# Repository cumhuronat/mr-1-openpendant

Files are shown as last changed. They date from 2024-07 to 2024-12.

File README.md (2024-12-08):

# mr-1-openpendant
An opensource pendant project for MR-1 CNC

## Overview
This project implements an open-source pendant system for the MR-1 CNC machine, providing a user-friendly interface for machine control and monitoring.
The system consists of two main components and detailed documentation for them can be found within their respective submodules.

### Pendant
- Custom-designed handheld controller
- Features a display interface for machine status and control
- Built using ESP32-based hardware
- Includes software implementation for the user interface and control logic

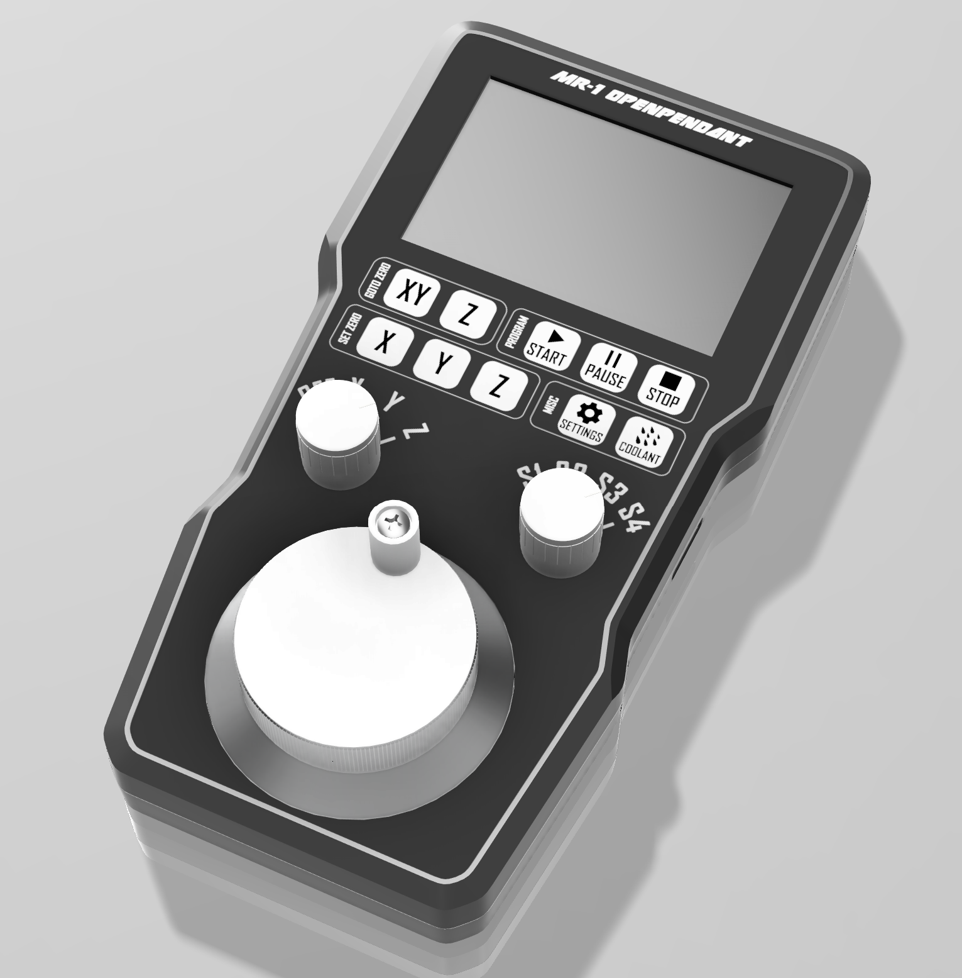
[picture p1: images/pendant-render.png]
Pendant Render

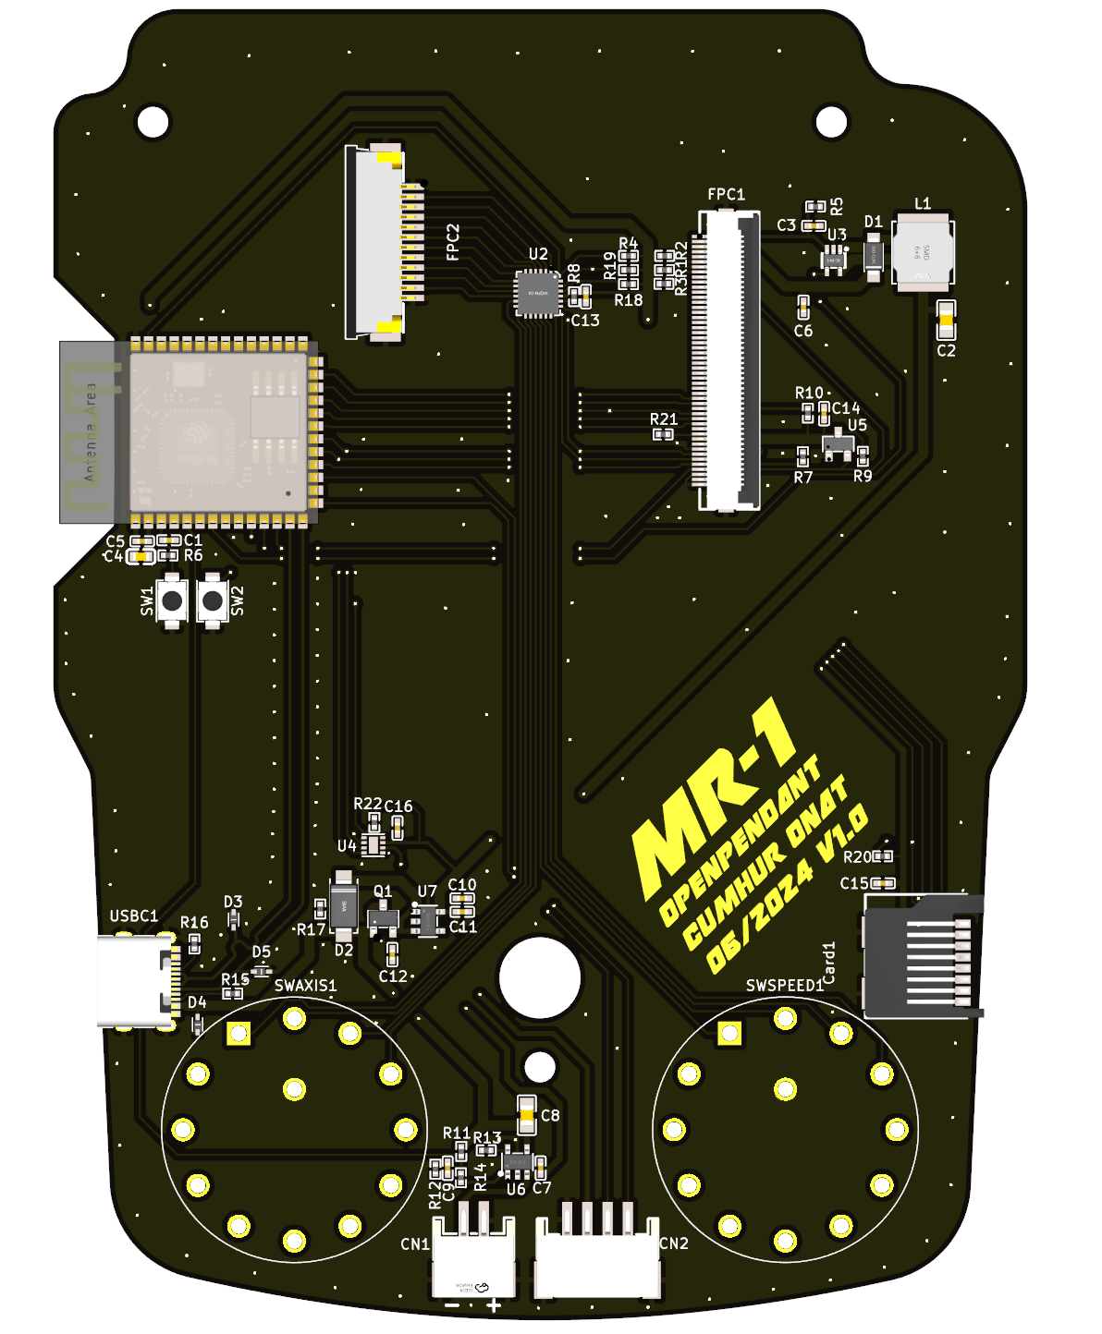
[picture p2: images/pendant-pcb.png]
Pendant PCB


### Dongle
- USB interface for CNC machine communication
- Components:
  - PCB design files
  - 3D-printable enclosure
  - Arduino-based firmware using TinyUSB
  - Interface software

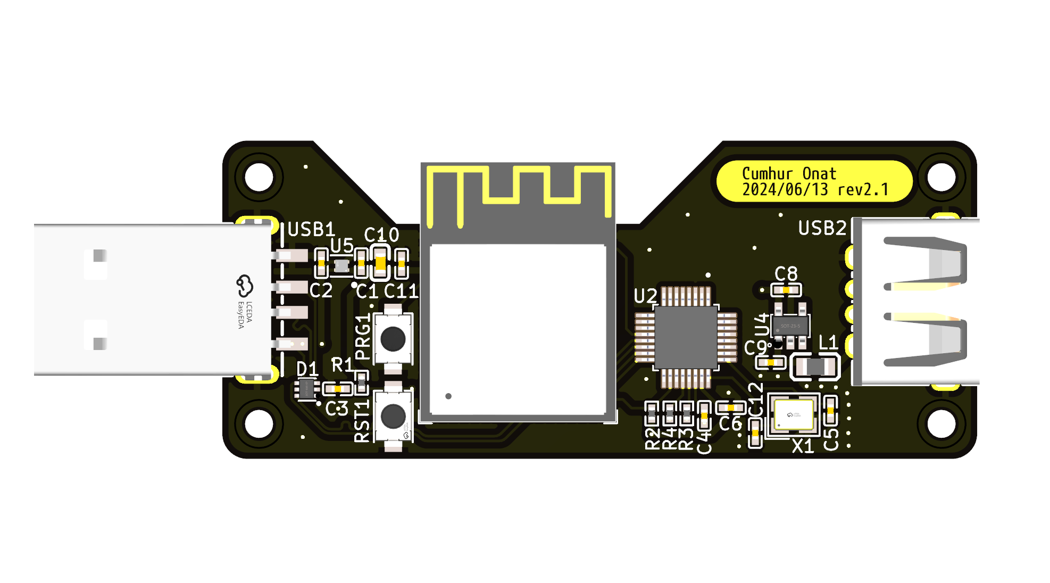
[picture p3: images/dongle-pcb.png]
Dongle PCB

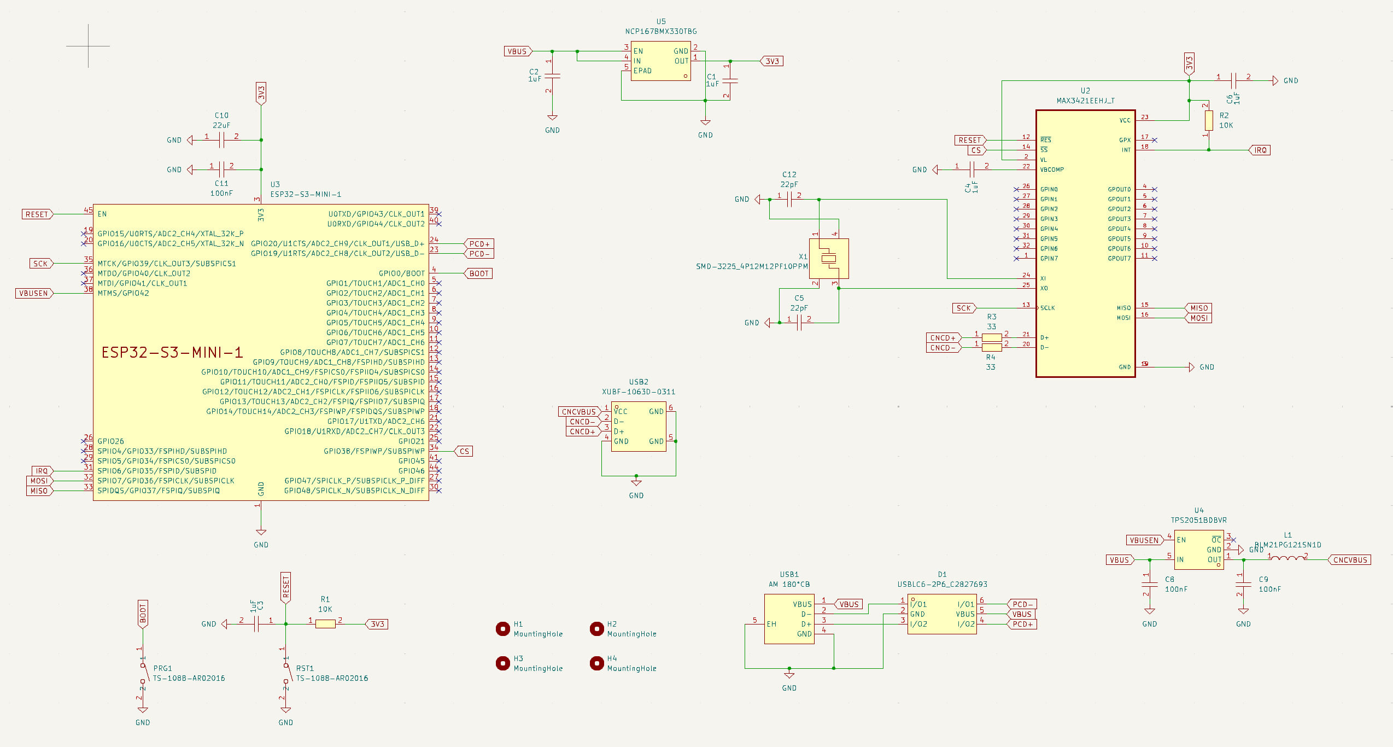
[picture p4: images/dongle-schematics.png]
Dongle Schematics


## Project Structure
- `/pendant` - Main pendant implementation
  - `/software` - Pendant firmware and interface code
- `/dongle` - USB interface dongle
  - `/enclosure` - 3D design files for the dongle case
  - `/pcb` - PCB design files
  - `/software` - Interface software

## Development Status
This project is currently under active development as part of the IMGD 5100 course final project.

## Acknowledgments
Special thanks to [Charlie Roberts](https://github.com/charlieroberts) for allowing this project to be developed as part of the IMGD 5100 final project.

## License
This project is open source and available under the[MIT License](https://opensource.org/licenses/MIT).

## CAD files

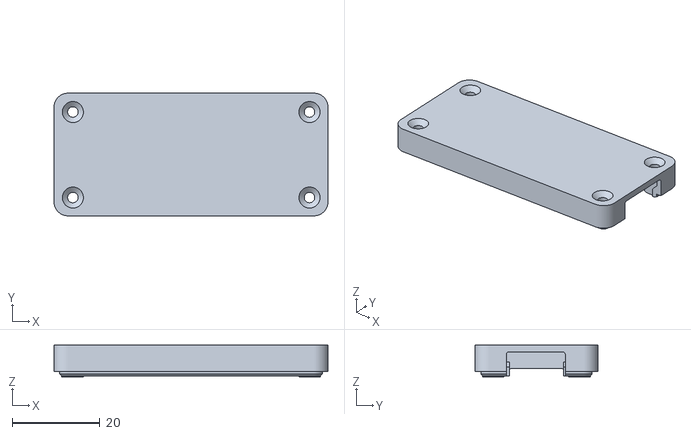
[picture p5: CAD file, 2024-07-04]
dongle/enclosure/top.stl
62.5 x 28.0 x 7.20

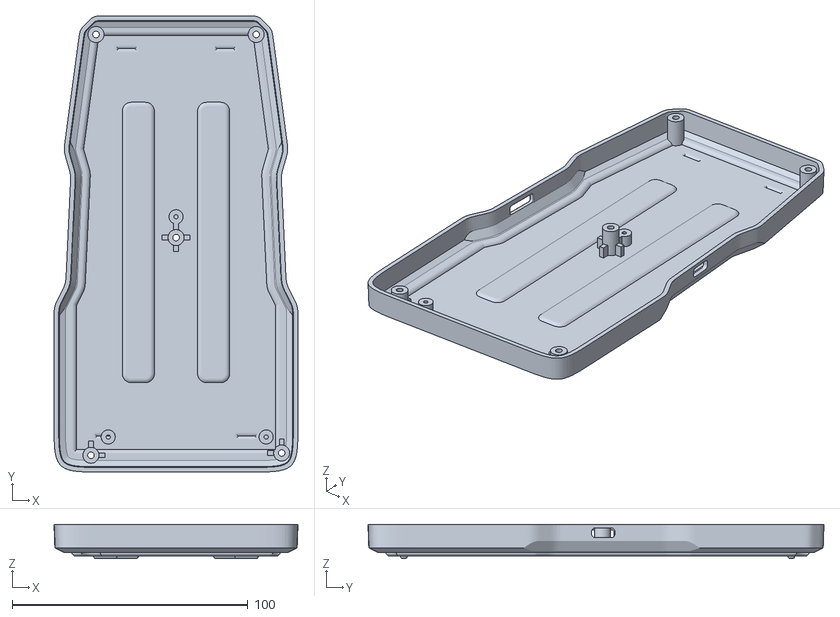
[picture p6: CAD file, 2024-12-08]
pendant/enclosure/BottomCover.stl
103.5 x 193.4 x 14.5

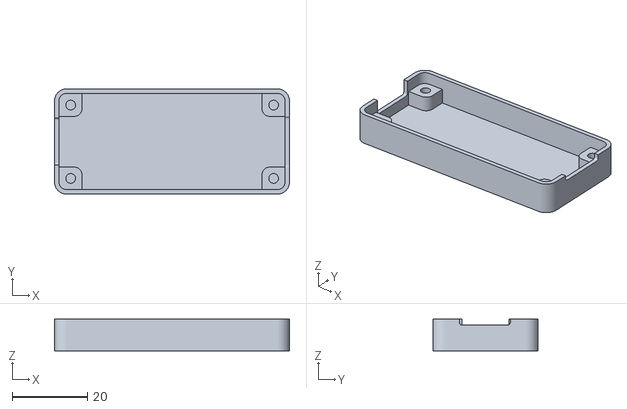
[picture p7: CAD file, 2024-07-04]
dongle/enclosure/bottom.stl
62.5 x 28.0 x 8.40

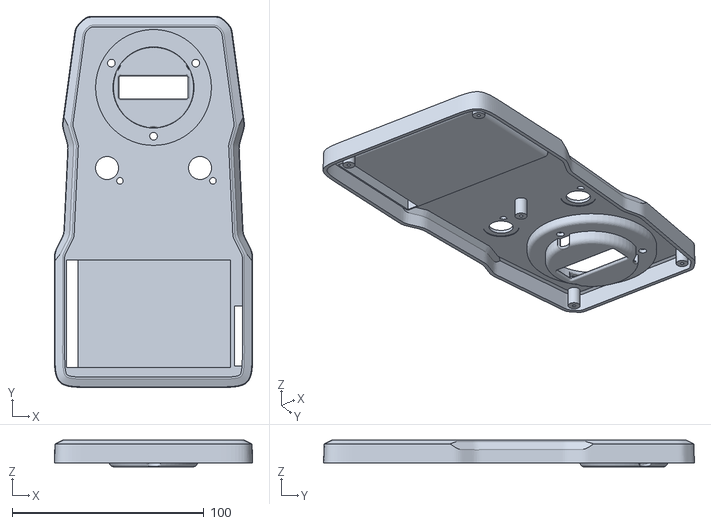
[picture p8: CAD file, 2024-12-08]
pendant/enclosure/TopCover.stl
103.5 x 193.4 x 14.0

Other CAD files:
dongle/enclosure/full.f3z

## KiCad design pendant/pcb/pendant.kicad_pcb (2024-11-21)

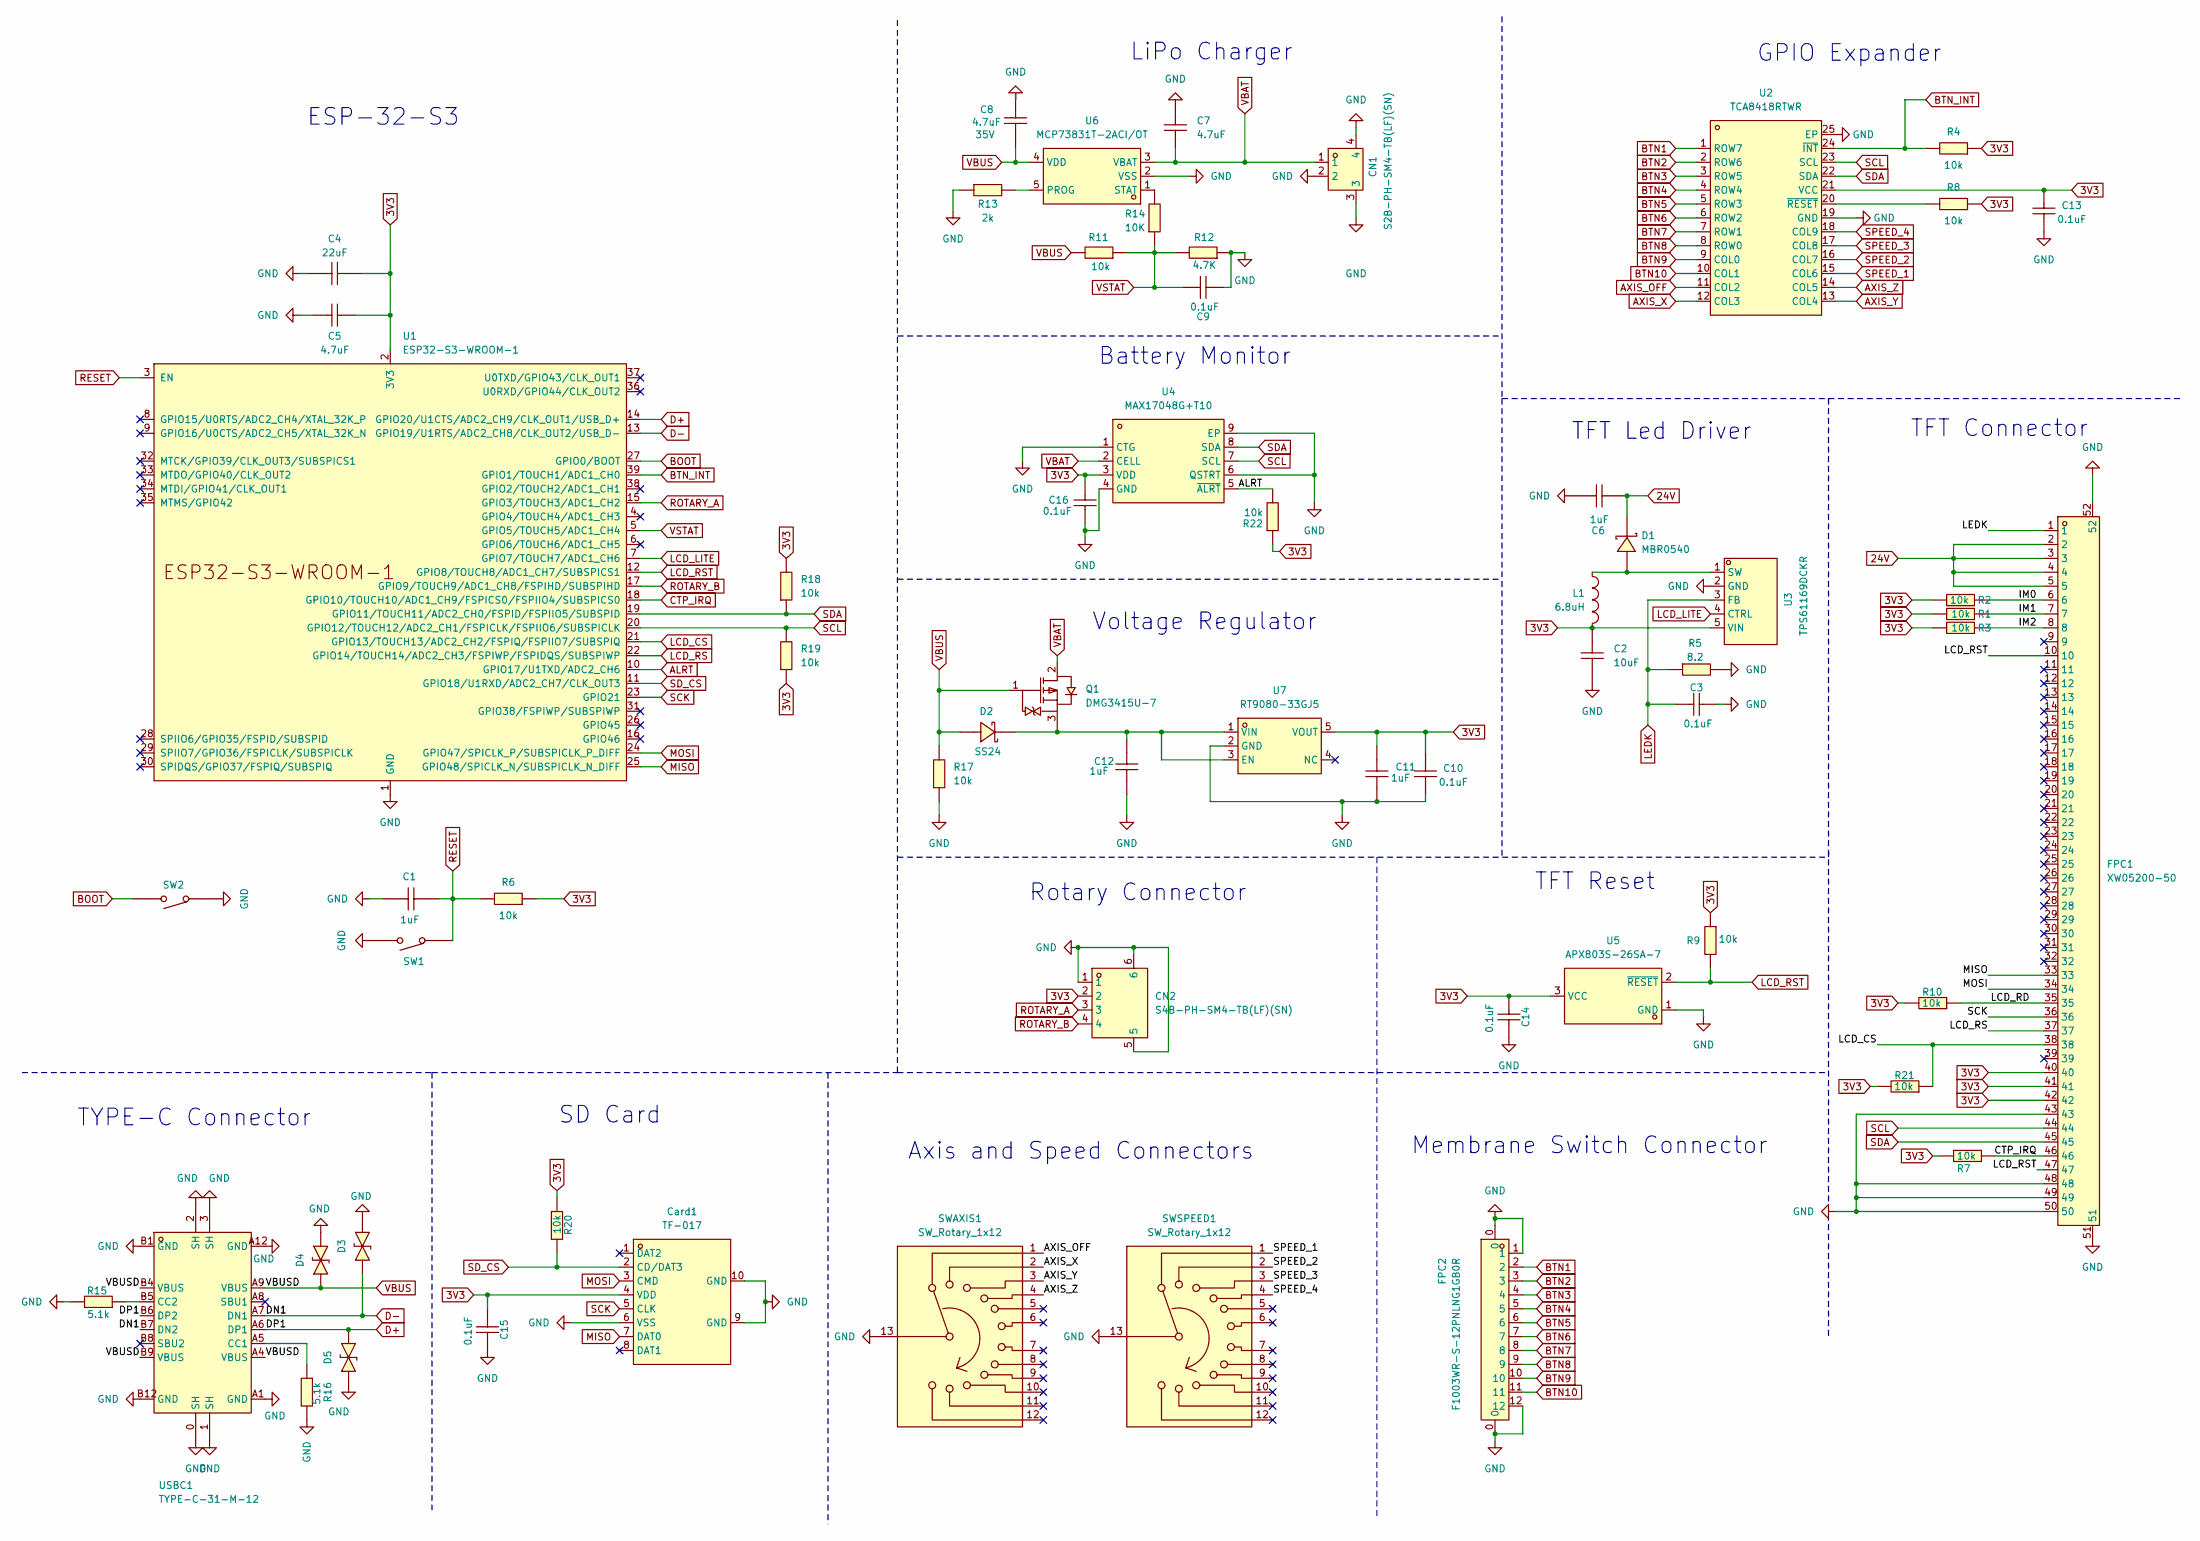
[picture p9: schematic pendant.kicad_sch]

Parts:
C1, C6, C11, C12: 1uF; C0402; LCSC Part C52923
C2: 10uF; C0805; LCSC Part C15850
C3, C9, C10, C13, C14, C15, C16: 0.1uF; C0402; LCSC Part C1525
C4: 22uF; C0603; LCSC Part C59461
C5, C7: 4.7uF; C0402; LCSC Part C23733
C8: 4.7uF; C0805; Voltage 35V; LCSC Part C668361
CN1: S2B-PH-SM4-TB(LF)(SN); CONN-SMD_P2.00_S2B-PH-SM4-TB-LF-SN; LCSC Part C295747
CN2: S4B-PH-SM4-TB(LF)(SN); CONN-SMD_S4B-PH-SM4-TB-LF-SN; LCSC Part C265102
Card1: TF-017; TF-SMD_TF-017; LCSC Part C410348
D1: MBR0540; SOD-123FL_L2.7-W1.8-LS3.8-RD; LCSC Part C116159
D2: SS24; SMA_L4.4-W2.8-LS5.4-R-RD; LCSC Part C489139
D3, D4, D5: LESD5D5.0CT1G; SOD-523_L1.2-W0.8-LS1.6-BI; LCSC Part C5246195
FPC1: XW05200-50; FPC-SMD_50P-P0.50_XW05200-50; LCSC Part C376073
FPC2: F1003WR-S-12PNLNG1GB0R; FPC-SMD_12P-P1.00_L5.5-W19.0; LCSC Part C247808
L1: 6.8uH; IND-SMD_L6.0-W6.0_SWPA6045S; LCSC Part C57254
Q1: DMG3415U-7; SOT-23-3_L2.9-W1.6-P1.90-LS2.8-BR-CW; LCSC Part C96616
R1, R2, R3, R4, R6, R7, R8, R9, R10, R11, R17, R18, R19, R20, R21, R22: 10k; R0402; LCSC Part C25744
R5: 8.2; R0402; LCSC Part C203098
R12: 4.7K; R0402; LCSC Part C140158
R13: 2k; R0402; LCSC Part C4109
R14: 10K; R0402; LCSC Part C25744
R15, R16: 5.1k; R0402; LCSC Part C25905
SW1, SW2: TS-1088-AR02016; SW-SMD_L3.9-W3.0-P4.45; LCSC Part C720477
SWAXIS1: SW_Rotary_1x12; CPA_12
SWSPEED1: SW_Rotary_1x12; CPA_12
U1: ESP32-S3-WROOM-1
U2: TCA8418RTWR; WQFN-24_L4.0-W4.0-P0.50-TL-EP2.5; LCSC Part C138713
U3: TPS61169DCKR; SC-70-5_L2.1-W1.3-P0.65-LS2.1-BR; LCSC Part C71045
U4: MAX17048G+T10; DFN-8_L2.0-W2.0-P0.50-BL-EP; LCSC Part C2682616
U5: APX803S-26SA-7; SOT-23-3_L2.9-W1.3-P1.83-LS2.4-BR; LCSC Part C526393
U6: MCP73831T-2ACI/OT; SOT-23-5_L3.0-W1.7-P0.95-LS2.8-BL; LCSC Part C424093
U7: RT9080-33GJ5; TSOT-23-5_L2.9-W1.6-P0.95-LS2.8-BL; LCSC Part C841192
USBC1: TYPE-C-31-M-12; USB-C_SMD-TYPE-C-31-M-12; LCSC Part C165948

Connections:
3V3: C2.2, C4.2, C5.2, C10.2, C11.1, C13.2, C14.1, C15.1, C16.1, CN2.2, Card1.4 (VDD), FPC1.40, FPC1.41, FPC1.42, L1.2, R1.2, R2.2, R3.2, R4.1, R6.1, R7.2, R8.1, R9.1, R10.2, R18.2, R19.1, R20.2, R21.2, R22.1, U1.2 (3V3), U2.21 (VCC), U3.5 (VIN), U4.3 (VDD), U5.3 (VCC), U7.5 (VOUT)
24V: C6.2, D1.1 (K), FPC1.2, FPC1.3, FPC1.4, FPC1.5
/IM0: FPC1.6, R2.1
/IM1: FPC1.7, R1.1
/IM2: FPC1.8, R3.1
/LCD_RD: FPC1.35, R10.1
ALRT: R22.2, U1.10 (GPIO17/U1TXD/ADC2_CH6), U4.5 (~ALRT)
AXIS_OFF: SWAXIS1.1, U2.11 (COL2)
AXIS_X: SWAXIS1.2, U2.12 (COL3)
AXIS_Y: SWAXIS1.3, U2.13 (COL4)
AXIS_Z: SWAXIS1.4, U2.14 (COL5)
BOOT: SW2.2, U1.27 (GPIO0/BOOT)
BTN1: FPC2.2, U2.1 (ROW7)
BTN2: FPC2.3, U2.2 (ROW6)
BTN3: FPC2.4, U2.3 (ROW5)
BTN4: FPC2.5, U2.4 (ROW4)
BTN5: FPC2.6, U2.5 (ROW3)
BTN6: FPC2.7, U2.6 (ROW2)
BTN7: FPC2.8, U2.7 (ROW1)
BTN8: FPC2.9, U2.8 (ROW0)
BTN9: FPC2.10, U2.9 (COL0)
BTN10: FPC2.11, U2.10 (COL1)
BTN_INT: R4.2, U1.39 (GPIO1/TOUCH1/ADC1_CH0), U2.24 (~INT)
CTP_IRQ: FPC1.46, R7.1, U1.18 (GPIO10/TOUCH10/ADC1_CH9/FSPICS0/FSPIIO4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)
D+: D5.1, U1.14 (GPIO20/U1CTS/ADC2_CH9/CLK_OUT1/USB_D+), USBC1.A6 (DP1), USBC1.B6 (DP2)
D-: D3.2, U1.13 (GPIO19/U1RTS/ADC2_CH8/CLK_OUT2/USB_D-), USBC1.A7 (DN1), USBC1.B7 (DN2)
GND: C1.2, C2.1, C3.2, C4.1, C5.1, C6.1, C7.2, C8.1, C9.2, C10.1, C11.2, C12.2, C13.1, C14.2, C15.2, C16.2, CN1.2, CN1.3, CN1.4, CN2.1, CN2.5, CN2.6, Card1.6 (VSS), Card1.9 (GND), Card1.10 (GND), D3.1, D4.1, D5.2, FPC1.43, FPC1.48, FPC1.49, FPC1.50, FPC1.51, FPC1.52, FPC2.0, FPC2.1, FPC2.12, R5.2, R12.1, R13.1, R15.2, R16.2, R17.1, SW1.2, SW2.1, SWAXIS1.13, SWSPEED1.13, U1.1 (GND), U1.40 (GND), U1.41 (GND), U2.19 (GND), U2.25 (EP), U3.2 (GND), U4.1 (CTG), U4.4 (GND), U4.6 (QSTRT), U4.9 (EP), U5.1 (GND), U6.2 (VSS), U7.2 (GND), USBC1.0 (SH), USBC1.1 (SH), USBC1.2 (SH), USBC1.3 (SH), USBC1.A1 (GND), USBC1.A12 (GND), USBC1.B1 (GND), USBC1.B12 (GND)
LCD_CS: FPC1.38, R21.1, U1.21 (GPIO13/TOUCH13/ADC2_CH2/FSPIQ/FSPIIO7/S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)
LCD_LITE: U1.7 (GPIO7/TOUCH7/ADC1_CH6), U3.4 (CTRL)
LCD_RS: FPC1.37, U1.22 (GPIO14/TOUCH14/ADC2_CH3/FSPIWP/FSPIDQS/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)
LCD_RST: FPC1.10, FPC1.47, R9.2, U1.12 (GPIO8/TOUCH8/ADC1_CH7/SUBSPICS1), U5.2 (~RESET)
LEDK: C3.1, FPC1.1, R5.1, U3.3 (FB)
MISO: Card1.7 (DAT0), FPC1.33, U1.25 (GPIO48/SPICLK_N/SUBSPICLK_N_DIFF)
MOSI: Card1.3 (CMD), FPC1.34, U1.24 (GPIO47/SPICLK_P/SUBSPICLK_P_DIFF)
unnamed: D1.2 (A), L1.1, U3.1 (SW)
unnamed: C12.1, D2.2 (K), Q1.3 (S), U7.1 (VIN), U7.3 (EN)
unnamed: R8.2, U2.20 (~RESET)
unnamed: R13.2, U6.5 (PROG)
unnamed: R14.2, U6.1 (STAT)
unnamed: R16.1, USBC1.A5 (CC1)
unnamed: R15.1, USBC1.B5 (CC2)
RESET: C1.1, R6.2, SW1.1, U1.3 (EN)
ROTARY_A: CN2.3, U1.15 (GPIO3/TOUCH3/ADC1_CH2)
ROTARY_B: CN2.4, U1.17 (GPIO9/TOUCH9/ADC1_CH8/FSPIHD/SUBSPIHD)
SCK: Card1.5 (CLK), FPC1.36, U1.23 (GPIO21)
SCL: FPC1.44, R19.2, U1.20 (GPIO12/TOUCH12/ADC2_CH1/FSPICLK/FSPIIO6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), U2.23 (SCL), U4.7 (SCL)
SDA: FPC1.45, R18.1, U1.19 (GPIO11/TOUCH11/ADC2_CH0/FSPID/FSPIIO5/S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), U2.22 (SDA), U4.8 (SDA)
SD_CS: Card1.2 (CD/DAT3), R20.1, U1.11 (GPIO18/U1RXD/ADC2_CH7/CLK_OUT3)
SPEED_1: SWSPEED1.1, U2.15 (COL6)
SPEED_2: SWSPEED1.2, U2.16 (COL7)
SPEED_3: SWSPEED1.3, U2.17 (COL8)
SPEED_4: SWSPEED1.4, U2.18 (COL9)
VBAT: C7.1, CN1.1, Q1.2 (D), U4.2 (CELL), U6.3 (VBAT)
VBUS: C8.2, D2.1 (A), D4.2, Q1.1 (G), R11.2, R17.2, U6.4 (VDD), USBC1.A4 (VBUS), USBC1.A9 (VBUS), USBC1.B4 (VBUS), USBC1.B9 (VBUS)
VSTAT: C9.1, R11.1, R12.2, R14.1, U1.5 (GPIO5/TOUCH5/ADC1_CH4)

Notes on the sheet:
Axis and Speed Connectors
ESP-32-S3
Rotary Connector
Battery Monitor
TFT Reset
SD Card
Membrane Switch Connector
LiPo Charger
TYPE-C Connector
GPIO Expander
Voltage Regulator
TFT Connector
TFT Led Driver

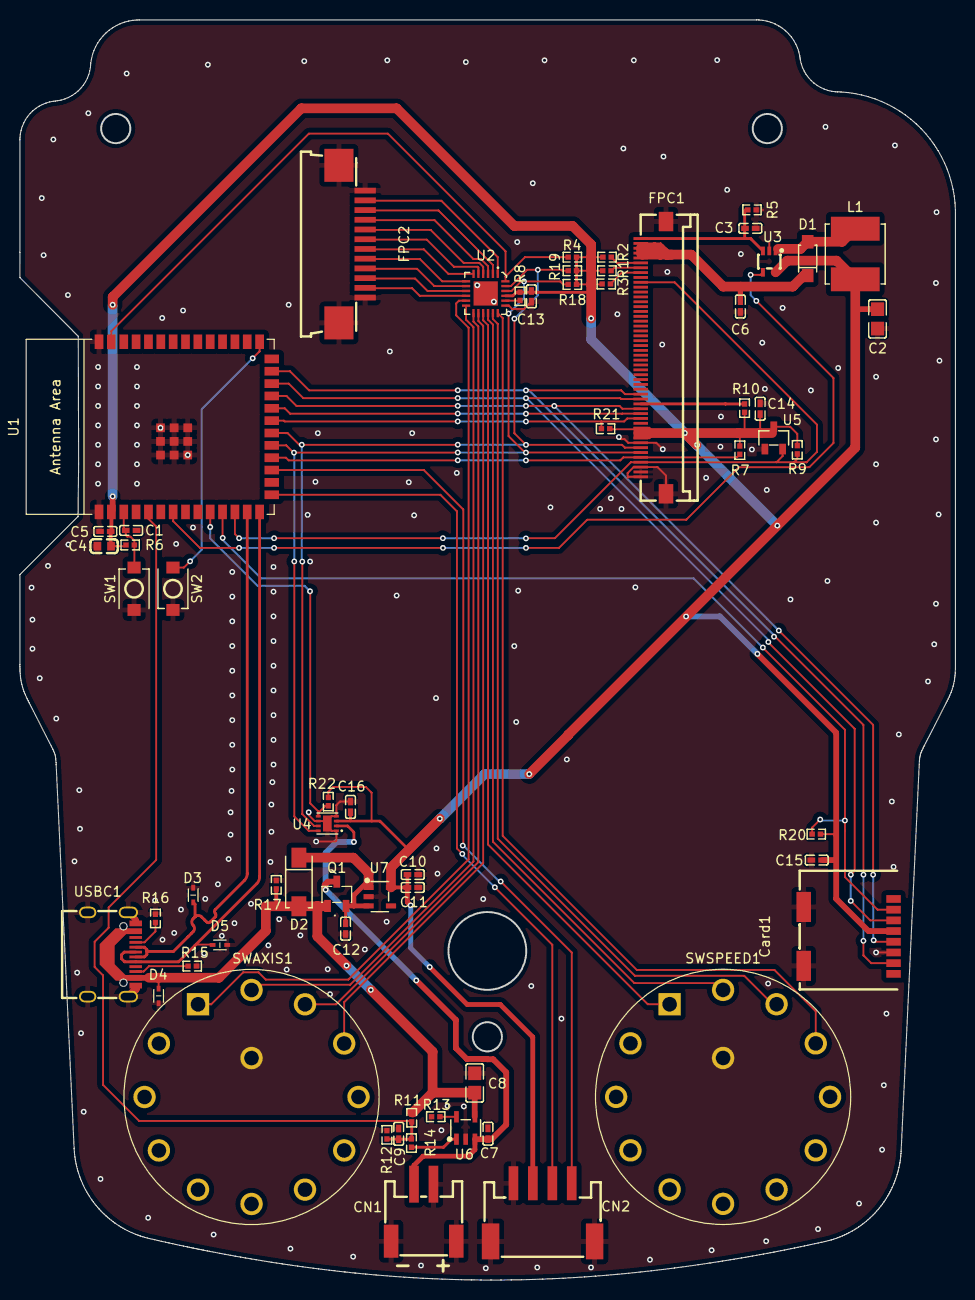
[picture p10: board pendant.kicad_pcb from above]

Board: 2 copper layers, 96.2 x 129.6 mm, 62 parts (0 on the bottom side), 55 nets.

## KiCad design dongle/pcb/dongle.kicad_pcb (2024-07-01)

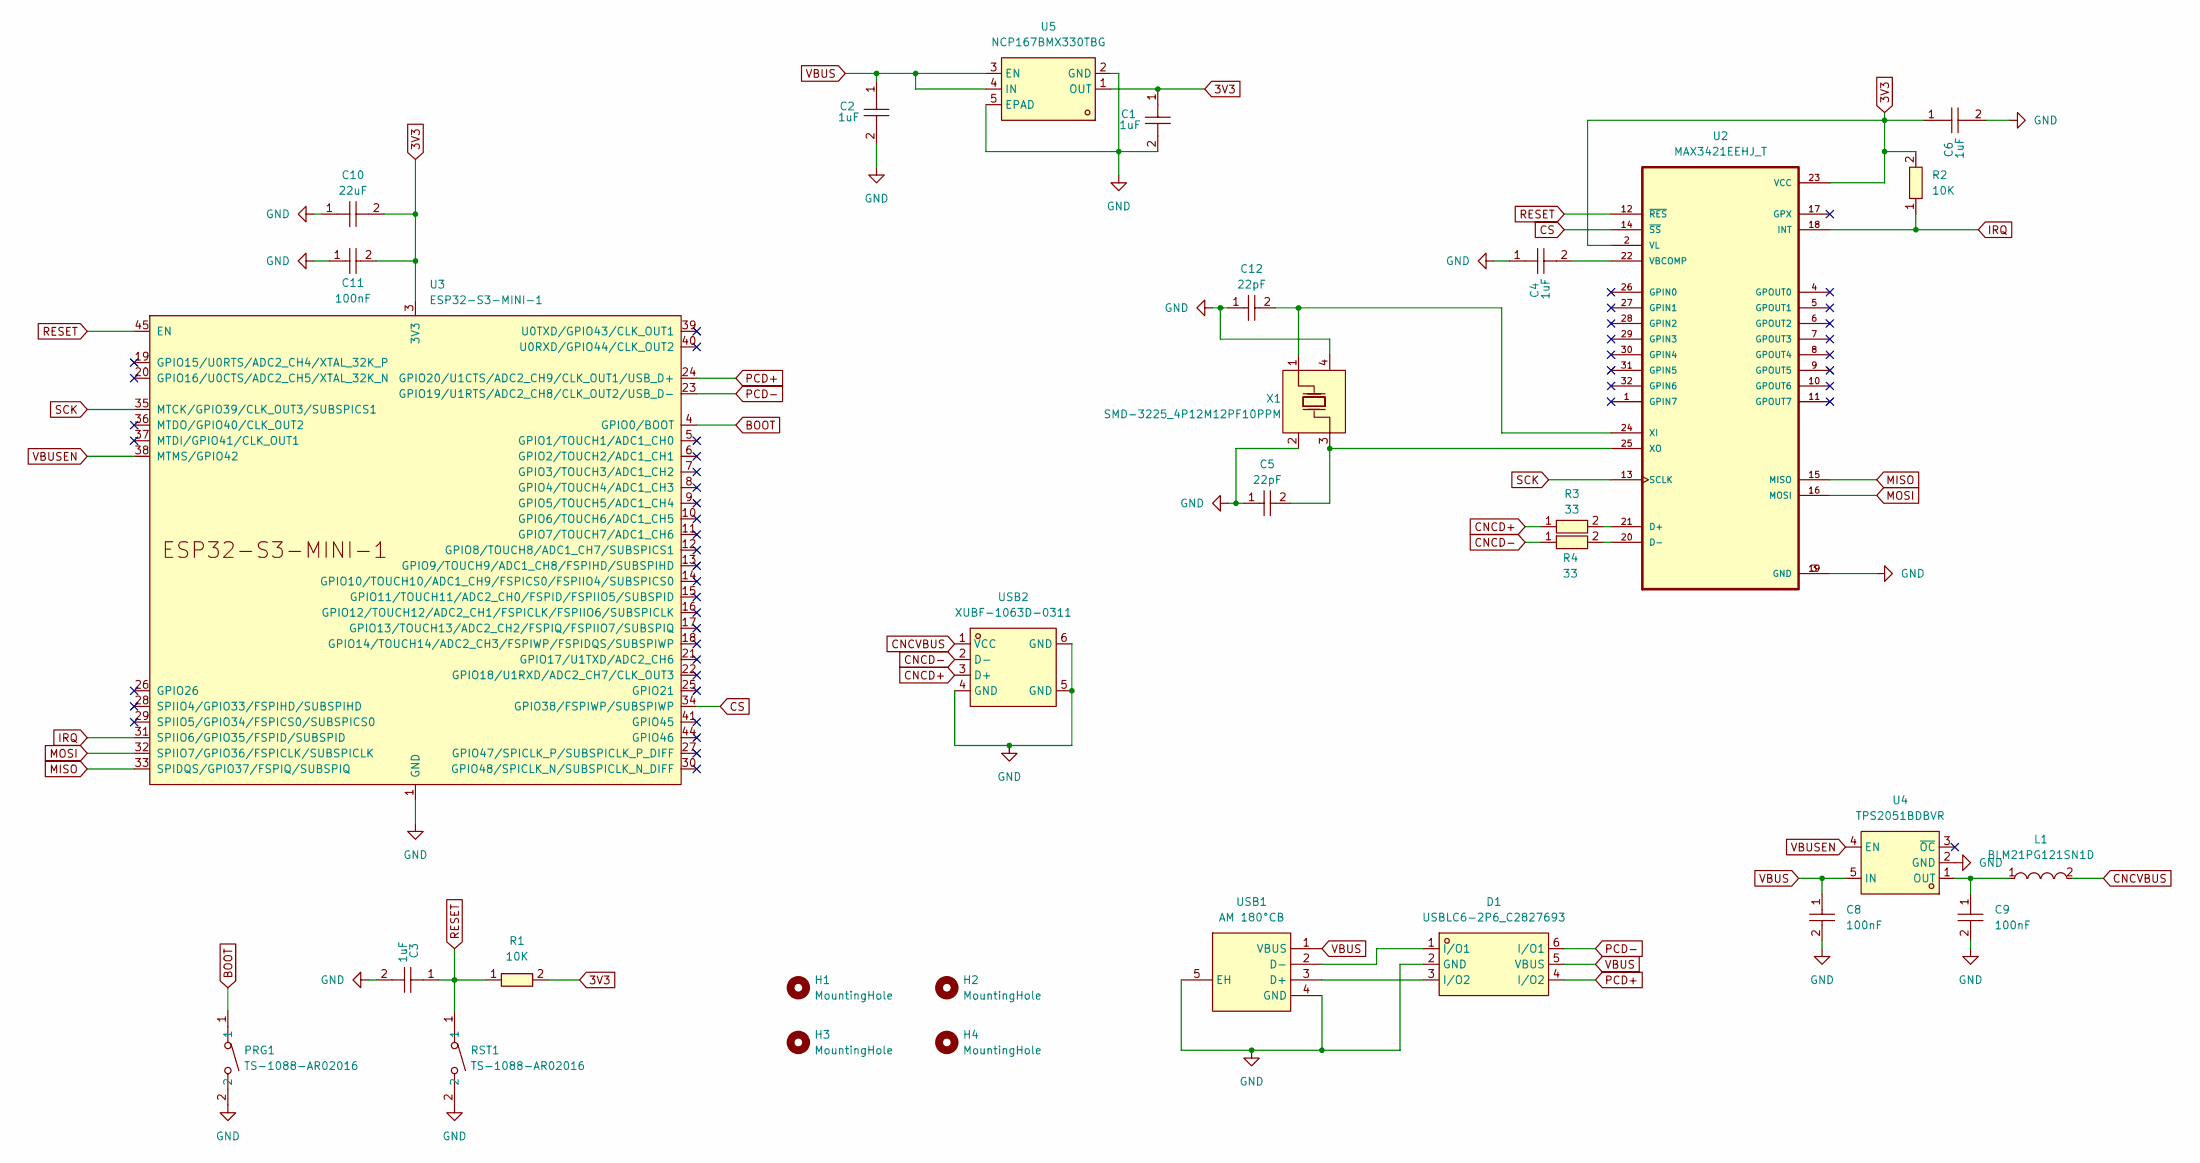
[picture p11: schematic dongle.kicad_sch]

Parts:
C1, C2, C3, C4, C6: 1uF; C0402; LCSC Part C52923
C5, C12: 22pF; C0402; LCSC Part C1555
C8, C9, C11: 100nF; C0402; LCSC Part C1525
C10: 22uF; C0603; LCSC Part C59461
D1: USBLC6-2P6_C2827693; SOT-666-6_L1.6-W1.2-P0.50-LS1.6-BL; LCSC Part C2827693
H1, H2, H3, H4: MountingHole; MountingHole_2.2mm_M2_DIN965
L1: BLM21PG121SN1D; L0805; LCSC Part C79382
PRG1: TS-1088-AR02016; SW-SMD_L3.9-W3.0-P4.45; LCSC Part C720477
R1, R2: 10K; R0402; LCSC Part C25744
R3, R4: 33; R0402; LCSC Part C25105
RST1: TS-1088-AR02016; SW-SMD_L3.9-W3.0-P4.45; LCSC Part C720477
U2: MAX3421EEHJ_T; QFP50P700X700X120-32N
U3: ESP32-S3-MINI-1
U4: TPS2051BDBVR; SOT-23-5_L3.0-W1.7-P0.95-LS2.8-BR; LCSC Part C24593
U5: NCP167BMX330TBG; onsemi-711AJ-03_2022-C-MFG; LCSC Part C892227
USB1: AM 180°CB; USB-SMD_AM180CB; LCSC Part C2681565
USB2: XUBF-1063D-0311; USB-A-TH_XUBF-1063D-0311; LCSC Part C7527653
X1: SMD-3225_4P12M12PF10PPM; CRYSTAL-SMD_4P-L3.2-W2.5-BL; LCSC Part C133337

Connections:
3V3: C1.1, C6.1, C10.2, C11.2, R1.2, R2.2, U2.2 (VL), U2.23 (VCC), U3.3 (3V3), U5.1 (OUT)
BOOT: PRG1.1, U3.4 (GPIO0/BOOT)
CNCD+: R3.1, USB2.3 (D+)
CNCD-: R4.1, USB2.2 (D-)
CNCVBUS: L1.2, USB2.1 (VCC)
CS: U2.14 (~SS), U3.34 (GPIO38/FSPIWP/SUBSPIWP)
GND: C1.2, C2.2, C3.2, C4.1, C5.1, C6.2, C8.2, C9.2, C10.1, C11.1, C12.1, D1.2 (GND), PRG1.2, RST1.2, U2.3 (GND), U2.19 (GND), U3.1 (GND), U3.2 (GND), U3.42 (GND), U3.43 (GND), U3.46 (GND), U3.47 (GND), U3.48 (GND), U3.49 (GND), U3.50 (GND), U3.51 (GND), U3.52 (GND), U3.53 (GND), U3.54 (GND), U3.55 (GND), U3.56 (GND), U3.57 (GND), U3.58 (GND), U3.59 (GND), U3.60 (GND), U3.61 (GND), U3.62 (GND), U3.63 (GND), U3.64 (GND), U3.65 (GND), U4.2 (GND), U5.2 (GND), U5.5 (EPAD), USB1.4 (GND), USB1.5 (EH), USB2.4 (GND), USB2.5 (GND), USB2.6 (GND), X1.2 (GND), X1.4 (GND)
IRQ: R2.1, U2.18 (INT), U3.31 (SPIIO6/GPIO35/FSPID/SUBSPID)
MISO: U2.15 (MISO), U3.33 (SPIDQS/GPIO37/FSPIQ/SUBSPIQ)
MOSI: U2.16 (MOSI), U3.32 (SPIIO7/GPIO36/FSPICLK/SUBSPICLK)
unnamed: R3.2, U2.21 (D+)
unnamed: R4.2, U2.20 (D-)
unnamed: C4.2, U2.22 (VBCOMP)
unnamed: C12.2, U2.24 (XI), X1.1 (OSC1)
unnamed: C5.2, U2.25 (XO), X1.3 (OSC2)
unnamed: C9.1, L1.1, U4.1 (OUT)
unnamed: D1.3 (I/O2), USB1.3 (D+)
unnamed: D1.1 (I/O1), USB1.2 (D-)
PCD+: D1.4 (I/O2), U3.24 (GPIO20/U1CTS/ADC2_CH9/CLK_OUT1/USB_D+)
PCD-: D1.6 (I/O1), U3.23 (GPIO19/U1RTS/ADC2_CH8/CLK_OUT2/USB_D-)
RESET: C3.1, R1.1, RST1.1, U2.12 (~RES), U3.45 (EN)
SCK: U2.13 (SCLK), U3.35 (MTCK/GPIO39/CLK_OUT3/SUBSPICS1)
VBUS: C2.1, C8.1, D1.5 (VBUS), U4.5 (IN), U5.3 (EN), U5.4 (IN), USB1.1 (VBUS)
VBUSEN: U3.38 (MTMS/GPIO42), U4.4 (EN)

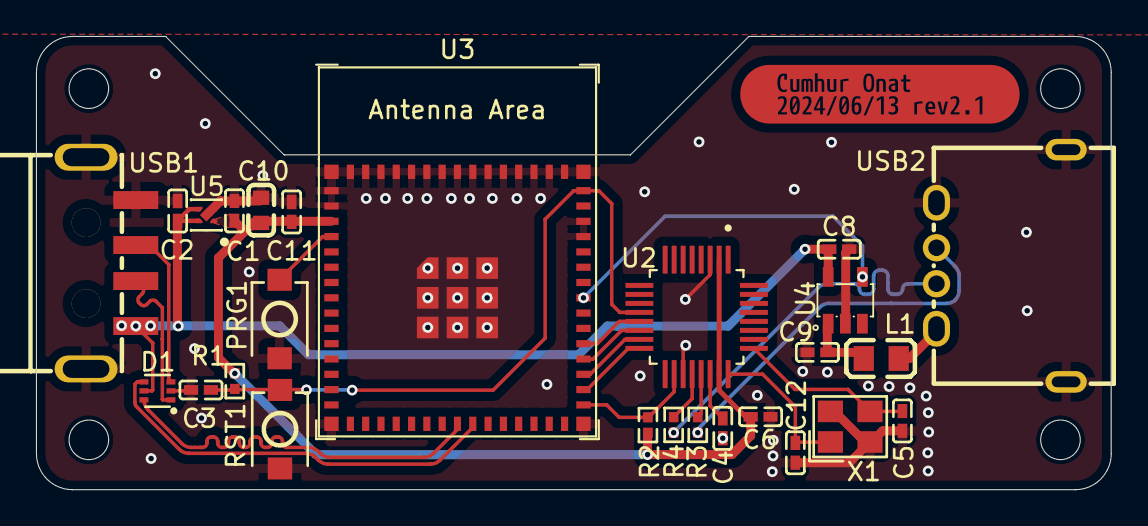
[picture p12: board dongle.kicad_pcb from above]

Board: 2 copper layers, 59.7 x 25.2 mm, 31 parts (0 on the bottom side), 24 nets.

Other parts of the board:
kibuzzard-666B8349: G***; kibuzzard-666B8349

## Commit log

2024-06-30 initial test for serial bridge
    [partitions.csv]
2024-07-01 fix race conditions in threads
2024-07-01 kicad project for the dongle
    [dongle.kicad_pcb, dongle.kicad_sch]
2024-07-02 grbl status parser wip
2024-07-04 pcb for pendant
    [pendant.kicad_pcb, pendant.kicad_sch]
2024-07-09 fix errors on pendant pcb
    [pendant.kicad_pcb, pendant.kicad_sch]
2024-11-21 update pendant pcb
    [pendant.kicad_pcb, pendant.kicad_sch]
2024-11-21 add fusion project for pendant enclosure
2024-12-08 new enclosure
    [BottomCover.stl, TopCover.stl]
